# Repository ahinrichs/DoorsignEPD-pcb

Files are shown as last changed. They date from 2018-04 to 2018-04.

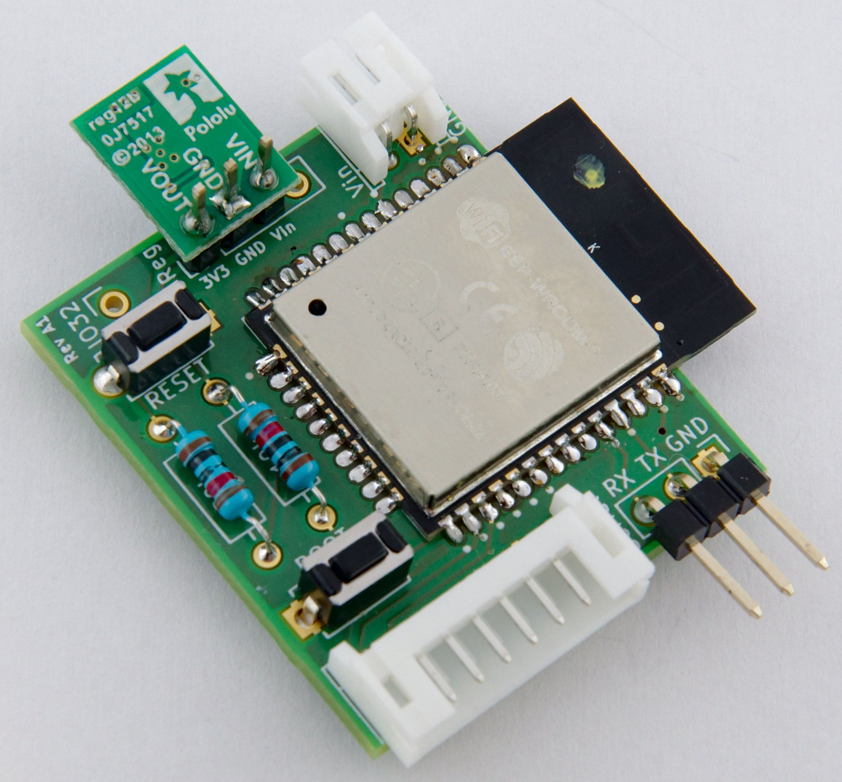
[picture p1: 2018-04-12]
docs/img/front.jpg

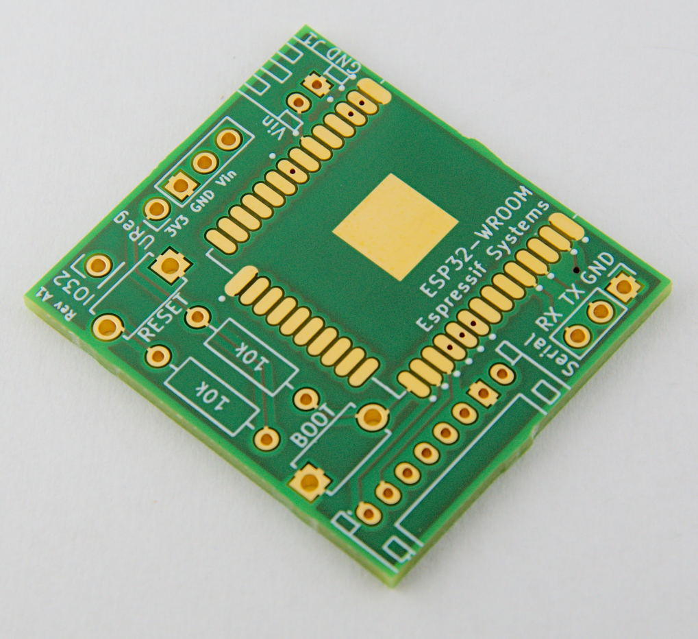
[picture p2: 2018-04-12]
docs/img/pcbsample.jpg

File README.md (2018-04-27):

## DoorsignEPD-pcb

ESP-WROOM-32 breakout board to connect it to a Waveshare E-Ink display. 

PCB

Inspired by article [Ausdauernde Infotafel](https://ct.de/yrzv) from German
computer magazine [c't](https://ct.de). Example arduino and server software can
be found [here](https://github.com/jamct/DoorsignEPD/).

Input voltage is connected to a voltage regulator jack and directly to
Pin6/IO34/ADC6 for monitoring. Hence input voltage must be below 3.6V.  I use
2xAA together with a step up regulator. Additionally I connected a pad for
Pin8/IO32/ADC4/TOUCH9. Haven't used it yet. Maybe for a touch wakeup or status
LED.

Display connector pin assignment is identical to the Waveshare hat connector.

Rev A2 PCB can be ordered e.g. via aisler.net: https://aisler.net/p/HSIWEKKI

Components needed in addition to PCB:

* Of course an ESP-WROOM-32 (or footprint compatible)
* Waveshare E-Ink display
* 3.3V voltage regulator or other 3.3V source
* Battery + holder of your choice
* 2x ~10kΩ pullup resistors R1+R2
* 2x tactile switch (included in aisler precious parts)
* 1x JST-PH 8 connector header+housing (included in aisler precious parts)
* 1x JST-PH 2 connector header+housing (included in aisler precious parts)
* 10-15 JST-PH terminals (included in aisler precious parts)
* Crimp tool for JST-PH connectors
* 3.3V capable USB-TTL adapter for programming

### Programming

This a minimalistic board to save power. No USB included. So you need an
USB-TTL adapter that is capable of doing 3.3V. [This one](https://www.amazon.de/WINGONEER-CP2104-seriell-Konverter-TTL-kompatibel/dp/B01CYBHM26) works for me under
Linux.

To upload an arduino sketch/flash firmware:

1. Connect the USB-Adapter GND/RX/TX to the board. Most adapters need RX board/TX adapter and TX board/RX adapter. If that doesn't work try RX/RX+TX/TX. To check press the Reset button. The serial monitor must show the ESP33 boot log.
2. Press and hold the Boot(loader) button, shortly press the Reset button, then release the Boot button. Log should show the ESP32 entering bootloader mode.
3. Now stop any serial monitor (Arduino IDE does this automatically)
4. Upload the sketch and wait until completion
5. Again press the Reset button
6. Restart serial monitor (Arduino IDE does this automatically)

### Assembled board

Assembled

### Changelog

#### Rev A2 (minor)

* Trace width power supply + GND
* Via min size 0.65mm (=drill + 0.25mm)

#### Rev A1

* Initial revision

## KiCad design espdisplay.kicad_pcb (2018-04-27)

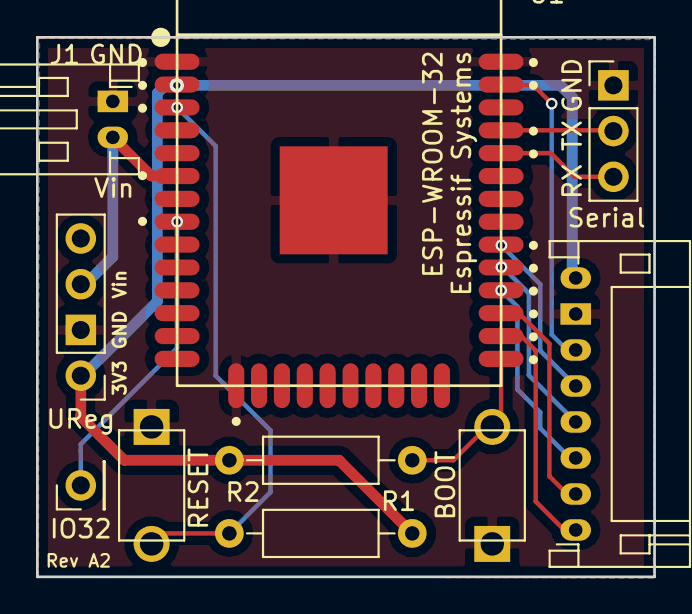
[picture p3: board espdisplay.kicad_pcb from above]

Board: 2 copper layers, 34.3 x 30.0 mm, 10 parts (0 on the bottom side), 14 nets.

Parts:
J1: PWR; JST_PH_S2B-PH-K_02x2.00mm_Angled
J2: UReg; Pin_UReg_1x04_Pitch2.54mm
J3: DOut; JST_PH_S8B-PH-K_08x2.00mm_Angled
J4: Serial; Pin_Header_Straight_1x03_Pitch2.54mm
J5: IO32; Pin_Header_Straight_1x01_Pitch2.54mm
R1, R2: 10k; R_Axial_DIN0207_L6.3mm_D2.5mm_P10.16mm_Horizontal
SW1: RESET; SW_Tactile_SPST_NO_6mmx3.5mm
SW2: BOOT; SW_Tactile_SPST_NO_6mmx3.5mm
U1: ESP-WROOM-32

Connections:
+3V3: J2.1, J3.8, R1.1, R2.1, U1.2
/BUSY: J3.1, U1.26
/CLK: J3.5, U1.30
/CS: J3.4, U1.29
/DC: J3.3, U1.28
/DIN: J3.6, U1.37
/IO32: J5.1, U1.8
/RST: J3.2, U1.27
/Vin: J1.2, J2.3, U1.6
GND: J1.1, J2.2, J3.7, J4.1, SW1.1, SW2.1, U1.1, U1.15, U1.38, U1.39
unnamed: J4.2, U1.35
unnamed: J4.3, U1.34
unnamed: R1.2, SW1.2, U1.3
unnamed: R2.2, SW2.2, U1.25

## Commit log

2018-04-12 Use global labels
    [espdisplay.kicad_pcb, espdisplay.sch]
2018-04-13 Revert "Use global labels"
    This reverts commit 96ed9b38a919df69e8aa619b2320596f596cf7ae.
    [espdisplay.kicad_pcb, espdisplay.sch]
2018-04-27 Vias 0.65mm
    [espdisplay.kicad_pcb]
2018-04-27 Trace width
    [espdisplay.kicad_pcb]
2018-04-27 Trace cleanup
    [espdisplay.kicad_pcb]
2018-04-27 "merge" rev.a2
    [espdisplay.kicad_pcb]

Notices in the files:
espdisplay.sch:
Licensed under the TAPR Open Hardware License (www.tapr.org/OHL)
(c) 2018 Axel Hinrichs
